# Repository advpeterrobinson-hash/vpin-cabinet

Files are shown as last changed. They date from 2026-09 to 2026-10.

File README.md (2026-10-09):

# Virtual Pinball Cabinet

## [OPEN THE CURRENT GALLERY →](docs/RENDERS.md)

**[ABRIR A GALERIA EM PORTUGUÊS →](docs/pt-BR/RENDERS.md)** · [Português (Brasil)](README.pt-BR.md)

**V35.1 is the current engineering / architectural review. CNC and manufacturing remain BLOCKED.** V32 is historical; passing CAD checks do not certify physical strength, purchased hardware fit or manufacturing readiness.

Parametric virtual pinball cabinet inspired by Williams WPC proportions, developed toward a reproducible flat-pack product with replaceable electronics.

## Current architecture — V35.1

The engineering review is maintained on `feat/v351-cncaudit-qn90f`. Read the [V35.1 technical report](https://github.com/advpeterrobinson-hash/vpin-cabinet/blob/aa3043cd172ed2bf0f05e0ef5ddcf1cbe9b53656/docs/STANDARD_WIDEBODY_V351.md) and [technical package](https://github.com/advpeterrobinson-hash/vpin-cabinet/blob/aa3043cd172ed2bf0f05e0ef5ddcf1cbe9b53656/exports/generated/widebody-v351/README.md). These links pin the reviewed evidence; they do not merge its CAD into `main`.

- Standard widebody: **628.65 mm** external body, **592.65 mm** nominal interior; **1308.10 mm** body length; **780 mm** backbox width.
- **66 wood components: 60 CNC plywood pieces and six solid blocks; 45 families.** Nominal plywood stock is **18 / 12 mm only**; actual lot measurement remains required.
- S1/S2/S3 removable shelves, T1/T2/T3 crossmembers and replaceable guides; low fixed PCBase, **no PC drawer**.
- Retained wooden-dowel/open-cradle playfield architecture. **Primary raised-playfield service support remains unresolved / HOLD**; no service-safety approval is implied.
- Commercial lockdown/receiver reference interfaces; siderails optional. Receiver fit/strategy remains unresolved where it controls permanent machining.
- Local **5 mm tempered playfield glass**, final size after cabinet/channel dry fit; actual side-channel profile and slot coupon still required.
- Real pinball legs; external removable mobility devices, no integrated wheels. Modular electronics and protected grounded mains distribution.

### Selected television — validation pending

**Samsung QN43QN90FAGXZD (QN90F 43-inch)** is the owner-selected purchase target. Selection does not establish compatibility: exact-envelope **PLAY / 0–50° service / 48 mm lift-out and interference checks must be rerun** before the QN90F is described as validated. The permanent cabinet remains intended for replaceable 42/43-inch-class displays.

## Review evidence and release gates

The report records 32 native-CAD review views and passing checks of the modeled reference state. Those results do not certify the selected QN90F, purchased hardware, material strength or human service safety. Preliminary nesting is a study, not production CAM.

**No CNC files are approved for manufacturing. Full-sheet release remains BLOCKED.** Open gates include receiver strategy/fit if machining-dependent; measured side channels and slot coupon; actual plywood lot and tolerance coupon; CNC-provider/tooling parameters and fit regeneration; remaining geometry-controlling hardware/control interfaces and attachment methods; exact QN90F rerun; primary raised-playfield support; and physical load/nudge/glass-edge/thermal qualification.

The lockdown bar and rear glass-channel screw locations are dry-fit interfaces with protected envelopes, not full-sheet CNC gates themselves. F06 reinforcement remains required and is qualified after shell dry fit. See the report for the precise gate boundaries.

## Documentation and history

- [Documentation index](docs/README.md) and [English gallery](docs/RENDERS.md).
- [Historical V32 gallery](https://github.com/advpeterrobinson-hash/vpin-cabinet/blob/feat/cabinet-review-v32/docs/RENDERS.md) and [V32 technical package](https://github.com/advpeterrobinson-hash/vpin-cabinet/blob/feat/cabinet-review-v32/exports/generated/cabinet-v32/README.md): 600 mm architecture, preserved as engineering history.
- [Contradictions and documentary resolutions](docs/PUBLIC_DOCUMENTATION_AUDIT.md).

Older width, gas-strut, sliding-PC and prop studies are historical context, not current V35.1 requirements. Scripts and revision-specific parameters remain engineering authority; no legacy build command on `main` certifies V35.1. Permanent structure should outlive replaceable electronics; adapters and carriers preserve serviceability.

## Open-source hardware

This project is released under the **CERN Open Hardware Licence Version 2 — Strongly Reciprocal (CERN-OHL-S-2.0)**.

Official project / Source Location:

**https://github.com/advpeterrobinson-hash/vpin-cabinet**

Commercial use is allowed. If you convey modified Covered Source or Products based on it, the applicable Complete Source and modifications must remain available under CERN-OHL-S-2.0, and the project Notices / Source Location must be preserved.

In short: **you may build and sell products based on the design, but conveyed improvements may not be turned into a closed proprietary fork.**

See [LICENSE](LICENSE), [NOTICE.md](NOTICE.md), the [open-source policy](docs/OPEN_SOURCE_POLICY.md), the [licensing FAQ](docs/LICENSING_FAQ.md), and [CONTRIBUTING.md](CONTRIBUTING.md).

The licence is intentionally **commercial-friendly but strongly reciprocal**: selling cabinets, kits, fabrication, installation, or support is allowed; when modified Covered Source or Products based on it are conveyed, the applicable Complete Source must stay available under the same reciprocal licence. "Free" here means the design/source remains freely available under the licence — it does **not** require physical products or services to be sold for zero price.

The official upstream project link is part of the project Notice and should remain with redistributed designs/products:

**https://github.com/advpeterrobinson-hash/vpin-cabinet**

## Contributing

Contributions are welcome from builders, CNC operators, mechanical designers, electricians, software developers, testers, and documentation writers.

- Start with [CONTRIBUTING.md](CONTRIBUTING.md).
- Read [GOVERNANCE.md](GOVERNANCE.md) for how engineering decisions are accepted.
- Use the GitHub issue templates for bugs, design proposals, manufacturing feedback, and hardware measurements.
- Use [SUPPORT.md](SUPPORT.md) for help and project-support boundaries.
- Report security or serious safety concerns through [SECURITY.md](SECURITY.md).
- Follow the [Code of Conduct](CODE_OF_CONDUCT.md).
- For reuse, forks, and commercial derivatives, read the [licensing FAQ](docs/LICENSING_FAQ.md).

Useful improvements are encouraged to come back upstream as pull requests, but the legal reciprocal obligations are governed by [LICENSE](LICENSE), not by whether a fork submits a PR.

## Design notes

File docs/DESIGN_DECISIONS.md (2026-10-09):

> **Historical architecture context — superseded by the [current V35.1 review](../README.md).** Earlier widths, display selections, gas-strut/prop and PC-drawer references below are retained for traceability, not current requirements. General safety, serviceability and flat-pack principles remain applicable. CNC/manufacturing remains BLOCKED. See the [documentation audit](PUBLIC_DOCUMENTATION_AUDIT.md).

# Design Decisions

This log records decisions that materially constrain the cabinet design. New decisions should be appended rather than silently rewriting history.

## DEC-001 — Preserve Williams WPC standard-body exterior

**Status:** superseded by DEC-013

Preserve the Williams WPC standard-body external cabinet proportions as the baseline instead of widening the cabinet to make the OLED easier to fit.

Baseline values:

- outer width: 558.80 mm
- side length: 1308.10 mm
- front outside height: 400.05 mm
- rear outside height: 596.90 mm
- rear top flat: 180.975 mm

**Reason at the time:** authentic proportions and compatibility with real-style pinball hardware were initially prioritized over maximizing interior width.

## DEC-002 — Metric plywood redesign

**Status:** accepted

Use nominal 18 mm plywood for the new parametric design instead of retaining the reference model's 19.05 mm / 12.70 mm imperial-stock assumptions.

At 18.00 mm main side thickness and 558.80 mm fixed outer width, nominal cabinet inside width is 522.80 mm.

**Manufacturing note:** the actual measured plywood thickness replaces 18.00 mm before production CNC files are approved.

## DEC-003 — LG OLED42C5 playfield

**Status:** accepted

Use LG OLED42C5 as the initial playfield display.

Engineering envelope used at this stage:

- native width: 932.0 mm
- native height: 540.0 mm
- maximum depth: 41.1 mm
- mass without stand: 9.8 kg
- VESA: 300 x 200 mm

When installed as a pinball playfield, the 540 mm dimension runs across the cabinet and the 932 mm dimension runs front-to-rear.

## DEC-004 — OLED side clearance pocket

**Status:** accepted for the current reference-width engineering baseline; subject to DEC-013 review before manufacturing

Use 1.0 mm nominal clearance per OLED side, yielding a 542.0 mm installed cross-width envelope.

At nominal 18 mm plywood and the historical 558.8 mm body width:

- cabinet inner width: 522.8 mm
- required side pocket depth: 9.6 mm each side
- remaining outer skin: 8.4 mm each side

The side pocket is clearance only. The reduced-thickness plywood is not permitted to carry the OLED or gas-strut structural loads.

## DEC-005 — Structural hinged OLED cradle

**Status:** accepted; geometry pending refinement

The OLED mounts to an independent cradle using its VESA interface. The cradle, not the OLED plastic chassis, carries hinge and lifting loads.

Required service features:

- rear pivot/hinge;
- dual gas struts;
- independent positive mechanical safety restraint/prop;
- controlled opening angle;
- cable service loop and strain relief;
- no slam-shut condition during service.

## DEC-006 — 32-inch 1080p backglass

**Status:** accepted

Use an inexpensive approximately 32-inch 1080p display for backglass duty. The project budget and engineering priority should favor playfield quality, force feedback, audio, and serviceability over backglass resolution.

## DEC-007 — Modular slide-out PC

**Status:** accepted

Use an open ATX metal chassis on a removable/full-extension drawer platform. Current reference chassis envelope is approximately 440 x 265 x 128 mm bare, with a larger reserved service envelope.

The drawer design must support future chassis replacement without redesigning the cabinet shell.

## DEC-008 — Force feedback and SSF are primary subsystems

**Status:** accepted

Mechanical feedback and SSF are design-driving subsystems rather than accessories to be fitted later.

- feedback toys mount rigidly and spatially appropriately;
- SSF-active wall areas remain clear of unnecessary rigid bracing;
- electronics shelves are modular and should avoid degrading cabinet-wall vibration;
- PC/electronics should be isolated from sharp mechanical shock where practical.

## DEC-009 — One external mains cord, multiple internal power domains

**Status:** accepted

The finished cabinet uses one grounded external mains connection and protected internal power distribution.

Operating states:

1. OFF
2. AUDIO ONLY / Bluetooth
3. FULL PINBALL

Audio-only mode must not require the PC, OLED, backglass, or mechanical DOF system to be powered.

## DEC-010 — Normally offline appliance

**Status:** accepted

After setup the cabinet is normally offline. Retain intentional service access through Ethernet and USB passthrough, but normal play must not depend on cloud connectivity.

## DEC-011 — Windows runtime, Linux/FreeCAD engineering

**Status:** provisional/accepted for current planning

Develop the cabinet CAD/tooling on Linux with FreeCAD and Git. The finished pinball computer is presently planned around Windows because the complete VPX/PinUP Popper/legacy DOF ecosystem is more mature there.

This decision may be revisited if the Linux pinball ecosystem reaches equivalent compatibility before software commissioning.

## DEC-012 — Cutter CNC consultation

**Status:** accepted

Cutter CNC (`cuttercnc.com`, Brazil) is the prospective CNC fabrication provider. Before manufacturing files are frozen, confirm their preferred file/layer conventions, available tooling, internal-radius requirements, two-sided registration process, material sourcing, and practical tolerances.

## DEC-013 — Future-proof electronics envelopes over exact historical dimensions

**Status:** accepted; supersedes DEC-001 where there is a conflict

The cabinet and structural metalwork are expected to outlive multiple generations of TVs, PC hardware, controller boards, amplifiers, and power supplies. Exact Williams dimensions are therefore a design reference rather than a manufacturing mandate.

The owner explicitly approves approximately **10–50 mm** dimensional deviations where they materially improve:

- future replacement compatibility;
- service access;
- structural margin;
- cable/connector access;
- modular mounting;
- availability of generic replacement hardware.

Permanent structure should use service envelopes and replaceable interfaces. Component-specific geometry should move into replaceable carriers, bezels, filler panels, and adapters where practical.

The main playfield cabinet width was subsequently selected at **580 mm** under DEC-015 to provide a larger future 42-inch-class service envelope while retaining the Williams visual character.

## DEC-014 — Future-proof backbox width and modular monitor carrier

**Status:** accepted for v0.6 engineering

Increase the backbox target outer width from the 730.25 mm reference to **780.0 mm**. This +49.75 mm deviation intentionally uses the owner-approved tolerance to avoid locking the cabinet to unusually narrow 31.5–32 inch displays.

Target monitor service envelope:

- width: 740 mm
- height: 450 mm
- depth: 100 mm

The permanent shell uses a removable/slotted monitor carrier plus a removable cosmetic bezel/filler panel. The exact backglass model is therefore not required before the permanent backbox shell is CNC-cut; it is only required before its carrier and bezel are finalized.

## DEC-015 — 580 mm CNC-flatpack main body

**Status:** accepted engineering baseline

Adopt **580.0 mm** as the main cabinet outer-width engineering baseline. The goal is not millimetre-perfect Williams replication; the goal is a long-lived, future-proof cabinet that can be replicated from CNC plans.

The target future playfield service envelope is approximately 560 × 950 × 55 mm with 2 mm installation clearance per side. The initial LG OLED42C5 remains comfortably inside that envelope.

A custom-width lockdown bar is explicitly acceptable and is not a blocker. Siderails, brackets, and other simple metal parts may likewise be supplied as dimensioned DXF/PDF fabrication drawings so a local shop can make them without requiring the builder to own metalworking equipment.

The final project should be buildable in an apartment from outsourced CNC/fabricated parts using ordinary hand tools rather than table saws, routers, drill presses, or welding equipment.

## DEC-016 — Replaceable service-I/O fascias with vintage white engraving

**Status:** accepted for v0.8 engineering

Use three service/control zones:

1. separated rear power fascia;
2. rear low-voltage service-I/O fascia;
3. hidden coin-door and under-front service/control panels.

Permanent cabinet panels receive simple rectangular service-bay openings. Connector-specific geometry belongs on small replaceable fascias/carriers so USB, HDMI, network, and other standards can be changed years later without recutting the cabinet.

The visual language is intentionally inspired by vintage hi-fi / laboratory equipment: dark wood or black-finished wood with shallow **white-filled CNC engraving** for connector names, borders, scales, and service legends.

Initial rear service ports are:

- RJ45 Ethernet (`NETWORK`);
- HDMI diagnostic output (`SERVICE DISPLAY`);
- USB-A (`USB SERVICE`);
- USB-C;
- one blank `RESERVE` position.

The rear mains bay remains physically separated and internally enclosed; the decorative wooden fascia is not relied upon as the electrical safety enclosure.

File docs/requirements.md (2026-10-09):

> **Historical architecture context — superseded by the [current V35.1 review](../README.md).** Earlier widths, display selections, gas-strut/prop and PC-drawer references below are retained for traceability, not current requirements. General safety, serviceability and flat-pack principles remain applicable. CNC/manufacturing remains BLOCKED. See the [documentation audit](PUBLIC_DOCUMENTATION_AUDIT.md).

# Cabinet Requirements

## Cabinet

Williams WPC standard-body proportions.

Main structural material:
- Metric plywood
- Nominal target: 18 mm
- Final CAD value must follow measured sheet thickness

Construction must prioritize:
- CNC cutting
- Self-aligning joints
- Minimal manual routing/drilling
- Modular service access
- Replaceable components

## Playfield

LG OLED42C5.

Requirements:
- Rigid independent cradle
- VESA-supported mounting
- Rear pivot/hinge
- Dual gas struts
- Mechanical safety prop or positive secondary restraint
- Service position approximately 60-75 degrees
- Cable service loop
- Playfield must not be structurally supported by OLED chassis

## Backglass

- Approx. 32-inch
- 1920x1080 acceptable
- Low-cost display preferred
- Removable/replaceable mounting system

## PC

- Open ATX test-bench/mining-style metal chassis
- Approximate known chassis size:
  440 x 265 x 128 mm
- Mounted to removable drawer/platform
- Full-extension locking slides
- GPU secondary support
- PC mechanically isolated from force-feedback structure

## Force Feedback

Priority subsystem.

Reserve mounting positions for:
- Flipper feedback
- Sling feedback
- Bumper/impact feedback
- Knocker
- Shaker
- Gear motor
- Additional DOF toys

Feedback devices should couple mechanically to cabinet structure.

## SSF

Reserve isolated cabinet-wall areas for:
- Front-left exciter
- Front-right exciter
- Rear-left exciter
- Rear-right exciter

Do not bridge these areas unnecessarily with rigid shelves.

## Electronics

Modular removable mounting panels for:
- Main controller
- DOF output boards
- LED controllers
- Powered USB hub
- Audio hardware
- DC distribution

Separate high-current and signal wiring routes.

## Power

One external mains cord.

Modes:
1. OFF
2. AUDIO ONLY
3. FULL PINBALL

Audio-only mode:
- PC OFF
- OLED OFF
- backglass OFF
- mechanical DOF OFF
- Bluetooth receiver ON
- main audio amplifier ON

## Service I/O

Front/underside:
- USB-A
- USB-A
- USB-C
- Hardware master volume

Rear:
- Ethernet
- USB service
- optional HDMI service
- main disconnect

## Mobility

- Real pinball legs
- Real levelers
- Wheels must retract or otherwise leave levelers firmly on floor during play
- Cabinet must remain rigid for nudging

## Manufacturing

Final manufacturing package should include:
- FreeCAD source
- DXF
- SVG where useful
- dimensioned PDF drawings
- assembly drawings
- CNC sheet layouts
- BOM
- electrical drawings

A CNC tolerance/material test coupon must be cut before cabinet production.

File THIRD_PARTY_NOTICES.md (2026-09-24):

# Third-Party Notices

The CERN-OHL-S-2.0 licence applies to original project material unless a file or directory states otherwise.

It does **not** relicense third-party material merely because that material is referenced by this repository.

This project may refer to or interoperate with third-party products, trademarks, dimensions, standards, software, documentation, and hardware, including pinball-industry components and commercial electronics. Those names and materials remain subject to their respective owners' rights and licences.

In particular:

- Williams and other pinball brands are referenced for compatibility, proportions, or historical context only;
- vendor manuals, datasheets, product images, and reference models retain their original copyright/licence status;
- third-party open-source software retains its own licence;
- commercial hardware part numbers do not imply sponsorship or endorsement.

Contributors must not copy proprietary CAD, copyrighted manuals, artwork, ROMs, game assets, trademarks, or other protected material into the project unless redistribution is clearly permitted and the source/licence is documented.

Project releases should prefer original geometry, measurements, interoperability facts, and links to lawful upstream sources rather than redistributing third-party files unnecessarily.

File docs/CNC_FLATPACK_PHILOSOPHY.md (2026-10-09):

> **Historical architecture context — superseded by the [current V35.1 review](../README.md).** Earlier widths, display selections, gas-strut/prop and PC-drawer references below are retained for traceability, not current requirements. General safety, serviceability and flat-pack principles remain applicable. CNC/manufacturing remains BLOCKED. See the [documentation audit](PUBLIC_DOCUMENTATION_AUDIT.md).

# CNC Flat-Pack Build Philosophy

## Primary project objective

The project is not only a one-off virtual pinball cabinet. It is intended to become a reproducible **CNC-first flat-pack cabinet system**.

A builder should be able to:

1. download the released plan package;
2. take the CNC files and material schedule to a local fabrication shop;
3. receive labeled, machined parts;
4. assemble, finish, wire, and commission the cabinet in an apartment or ordinary room;
5. do so without owning expensive woodworking or metalworking machinery.

The design should therefore move precision work from the builder to CAD/CAM and the fabrication shop.

## What the CNC shop should do

Where practical, the CNC package should include all repeatable woodworking operations:

- exterior panel profiles;
- through-cuts;
- dados and rabbets;
- tab/slot alignment geometry;
- pockets for display clearance and hardware;
- speaker, fan, button, coin-door and service openings;
- pilot/reference holes;
- threaded-insert/T-nut locations where appropriate;
- cable-pass openings;
- ventilation geometry;
- removable electronics-panel interfaces;
- PC-drawer mounting references;
- labels/part IDs or engraving marks where useful;
- test coupon for actual material thickness and fit.

Dogbone/T-bone relief and other router-specific geometry should be generated from confirmed provider tooling rather than improvised by the builder.

## What the builder should need

Target ordinary tools only:

- drill/driver;
- screwdrivers / hex keys;
- clamps;
- rubber mallet;
- wood glue;
- measuring tape / square;
- basic sanding and painting supplies;
- wire tools for electrical assembly.

A build step that requires a table saw, router table, precision handheld routing, drill press, welder, planer, or similar equipment should be treated as a design smell unless there is no practical outsourced/CNC alternative.

## Joinery strategy

Prefer joinery that is self-locating and forgiving:

- dados;
- rabbets;
- tabs and slots;
- captured shoulders;
- keyed left/right geometry;
- CNC-located fastener holes.

Avoid requiring the builder to establish critical dimensions by measuring from an edge with a tape measure.

The cabinet should naturally square itself during dry assembly as much as practical.

## Electronics and future replacement

Permanent cabinetry should not be tied to one generation of electronics.

Use broad service envelopes and replaceable interfaces:

- playfield TV: structural cradle + replaceable VESA/adapter plate + removable fillers;
- backglass: replaceable monitor carrier + replaceable bezel/filler panel;
- PC: fixed drawer infrastructure + replaceable chassis adapter plate;
- controllers/amplifiers/PSUs: removable electronics panels or grid/slot mounting;
- external ports: replaceable I/O panel;
- DMD/speaker area: replaceable module/panel.

Replacing electronics should normally require a new adapter/filler part, not destructive modification of the permanent cabinet.

## Metal parts

Custom metalwork is acceptable if it can also be outsourced from drawings.

Examples:

- custom-width lockdown bar;
- siderails;
- hinge brackets;
- gas-strut brackets;
- PC drawer brackets;
- wheel/retractable-caster mechanisms;
- service/I/O panels.

Where practical, provide DXF plus dimensioned PDF and fabrication notes so a local laser-cutting/bending/welding shop can reproduce the part.

The builder should not be expected to own metalworking machinery.

## Release package goal

A mature release should contain at least:

```text
release/
├── README-FIRST.pdf
├── BOM.xlsx
├── materials.pdf
├── assembly-manual.pdf
├── cnc/
│   ├── 18mm-sheet-01.dxf
│   ├── 18mm-sheet-02.dxf
│   ├── 12mm-sheet-01.dxf
│   ├── tolerance-coupon.dxf
│   └── layer-conventions.pdf
├── drawings/
│   ├── cabinet.pdf
│   ├── backbox.pdf
│   ├── playfield-cradle.pdf
│   └── electronics-layout.pdf
├── metal/
│   ├── lockdown-bar.dxf
│   ├── lockdown-bar.pdf
│   ├── hinge-brackets.dxf
│   └── hinge-brackets.pdf
└── config/
    └── design-baseline.json
```

The exact structure may evolve, but the final user should not need FreeCAD merely to build the cabinet.

## Design priority order

When objectives conflict, use this order unless safety requires otherwise:

1. safety;
2. reproducibility;
3. CNC manufacturability;
4. easy assembly with ordinary tools;
5. serviceability and future electronics replacement;
6. force-feedback/audio performance;
7. authentic Williams visual character;
8. millimetre-perfect historical dimensions.

This means a small dimensional deviation is desirable when it materially simplifies fabrication, strengthens the structure, improves replacement tolerance, or eliminates specialist-tool work at home.

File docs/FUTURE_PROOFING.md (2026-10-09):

> **Historical architecture context — superseded by the [current V35.1 review](../README.md).** Earlier widths, display selections, gas-strut/prop and PC-drawer references below are retained for traceability, not current requirements. General safety, serviceability and flat-pack principles remain applicable. CNC/manufacturing remains BLOCKED. See the [documentation audit](PUBLIC_DOCUMENTATION_AUDIT.md).

# Future-proofing policy

## Owner direction

The cabinet is expected to last much longer than its televisions, PC, controllers, amplifiers, and power electronics. Exact historical Williams dimensions are therefore secondary to long-term serviceability and replacement-part compatibility.

The owner explicitly accepts approximately 10–50 mm dimensional deviations when they materially improve the design.

## Permanent structure vs replaceable electronics

Permanent wood and metal structure should be sized around service envelopes and modular interfaces. Electronics-specific geometry belongs in replaceable parts where practical.

Preferred pattern:

- permanent shell: generous service envelope;
- replaceable carrier/adapter: actual VESA or chassis pattern;
- replaceable bezel/filler: closes cosmetic gaps;
- slotted mounting where practical;
- cable service loops and accessible connectors;
- no trapped electronics behind irreversible joinery.

## Backbox

The authentic reference backbox is 730.25 mm wide. This is too restrictive for many modern 31.5–32 inch displays.

v0.6 therefore targets 780 mm outer width and a 740 x 450 x 100 mm monitor service envelope. This is a deliberate +49.75 mm deviation from the reference width and remains within the owner-approved future-proofing allowance.

The exact backglass monitor is no longer required before cutting the permanent backbox shell. Only its replaceable monitor carrier and cosmetic bezel depend on the exact purchased model.

## Main playfield cabinet

The current 558.8 mm Williams reference body fits the selected LG OLED42C5 but leaves little cross-width growth margin once an 8 mm side skin is preserved.

Before main-cabinet dimensions are frozen, evaluate a modest width increase against:

- future 42-inch-class display chassis widths;
- desired minimum side skin;
- playfield glass sourcing;
- lockdown-bar sourcing/fabrication;
- siderail sourcing/fabrication;
- hinge/cradle width;
- flipper/button ergonomics;
- Williams visual proportions.

A likely evaluation range is roughly 570–575 mm external body width, but no new body width is approved until hardware consequences are checked parametrically.

## PC and electronics

The existing open-frame ATX chassis is an initial component, not a permanent dimensional constraint. The drawer uses a service envelope and a replaceable chassis adapter.

Controller boards, amplifiers, power supplies, and DOF boards should mount to removable grid/slotted panels or DIN-style subassemblies where appropriate so future boards can change size without cabinet surgery.

## Manufacturing rule

Do not spend structural margin merely to reproduce a historical dimension when 10–50 mm of additional envelope materially reduces future replacement risk.

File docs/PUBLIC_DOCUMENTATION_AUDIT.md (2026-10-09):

# Public documentation audit — V35.1

Audit performed before editing the public entry points. Main baseline: `2eed36e4ff6e0871edc4d7d845288c5a629fd8b9`. Engineering evidence: [`aa3043cd172ed2bf0f05e0ef5ddcf1cbe9b53656`](https://github.com/advpeterrobinson-hash/vpin-cabinet/blob/aa3043cd172ed2bf0f05e0ef5ddcf1cbe9b53656/docs/STANDARD_WIDEBODY_V351.md) on `feat/v351-cncaudit-qn90f`.

| Location before correction | Contradiction | Documentary resolution |
|---|---|---|
| main README.md and README.pt-BR.md | V32 called current; 600 mm body / 564 mm interior; links to V32 gallery | Identify V35.1 as current engineering review, 628.65 / 592.65 mm; retain V32 as history |
| main README.md and README.pt-BR.md | Captive props described as current mechanism | Do not prescribe an unqualified support; V35.1 primary raised-playfield support remains HOLD |
| Engineering-branch README.md | Opening says CURRENT V35.1, later headings say current V32; active design still lists 600 mm, custom lockdown and sliding CPU shelf | Main entry points link directly to pinned V35.1 report/package rather than treating the mixed branch README as authority |
| Engineering-branch docs/RENDERS.md and docs/pt-BR/RENDERS.md | V35.1, V34, V33.8 and V32 all called current | Provide bilingual main gallery pages with a single current V35.1 entry and explicitly historical V32 links |
| main AGENTS.md | 580 mm, LG C5, mandatory gas struts, PC drawer and play-isolated wheels | Add explicit current-review precedence; preserve old baseline instructions as historical evidence |
| main docs/FUTURE_PROOFING.md, docs/requirements.md, docs/DESIGN_DECISIONS.md and docs/CNC_FLATPACK_PHILOSOPHY.md | Older width studies, gas struts and drawer references read as active requirements | Mark superseded architecture context; general safety/flat-pack principles remain applicable |
| V35.1 report: passing motion checks vs QN90F purchase selection | Modeled reference checks could be mistaken for exact QN90F validation | Preserve exact-envelope PLAY / 0–50° / 48 mm lift-out rerun requirement; purchase selection is not validation |

## Scope and precedence

This correction targets `main` with documentation only. Engineering-branch README/gallery contradictions remain recorded above; their contents are not imported or rewritten by this PR. The pinned V35.1 technical report and generated package provide revision-specific evidence. Existing V32 and earlier artifacts remain historical, including their original validation results; those results do not transfer to V35.1.

No geometry, parameters, BOM, CAD, generated views or manufacturing files are changed. No engineering branch is merged. V35.1 identifies the current review, not a CNC-approved product. CERN-OHL-S-2.0, notices and contribution rules remain unchanged.

## Gates preserved

Exact Samsung QN43QN90FAGXZD envelope and service-motion/interference validation; primary raised-playfield support; receiver strategy/fit where it controls machining; measured side-channel profile and slot coupon; plywood lot/tolerance coupon; provider/tooling and fit regeneration; remaining permanent hardware/control interfaces and attachment methods; physical load, nudge, glass-edge and thermal qualification. Full-sheet CNC release remains **BLOCKED**.

Lockdown-bar and rear-channel screw locations are dry-fit interfaces with protected envelopes, not full-sheet CNC gates in themselves. F06 reinforcement is required but its jig/screw qualification follows shell dry fit; final 5 mm glass cutting follows cabinet/channel dry fit. Do not broaden these into unnecessary pre-CNC purchasing gates.

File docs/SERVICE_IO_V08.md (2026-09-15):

# Service I/O v0.8 — vintage engraved rear panels

Status: engineering provisional; not manufacturing-ready.

## Design intent

The external I/O should look like part of the cabinet rather than like a PC case. The chosen visual language is inspired by older hi-fi receivers, amplifiers, laboratory equipment, and arcade hardware: dark wood/black surfaces with small white legends, borders, scales, and connector names.

The cabinet is still a CNC-flatpack project, so the appearance must not depend on difficult hand fabrication. Precision openings and engraving belong in the CNC package; the builder should only need finishing, simple paint fill, and ordinary screw assembly.

## Core construction rule

Do **not** cut today's USB/HDMI/RJ45 connector shapes directly into permanent cabinet structure.

Instead use:

1. one simple rectangular CNC opening in the permanent rear panel;
2. a removable CNC-cut decorative wood fascia;
3. a thin replaceable connector carrier behind the fascia;
4. panel-mount pass-through connectors on the carrier;
5. CNC-engraved white-filled legends on the fascia.

If interface standards change later, the owner replaces the small fascia/carrier assembly rather than modifying the cabinet.

## Rear layout

Viewed from behind the 580 mm cabinet:

```text
┌──────────────────────────────────────────────────────────┐
│                                                          │
│                        REAR                              │
│                                                          │
│                                                          │
│   ┌────────────────┐        ┌────────────────────────┐   │
│   │    AC MAINS    │        │        SERVICE         │   │
│   │                │        │                        │   │
│   │ inlet / cord   │        │ NETWORK   HDMI         │   │
│   │ disconnect     │        │ USB-A     USB-C        │   │
│   │                │        │ RESERVE                │   │
│   └────────────────┘        └────────────────────────┘   │
│                                                          │
└──────────────────────────────────────────────────────────┘
```

### Power fascia

- 170 × 120 mm removable decorative fascia
- 35 mm from cabinet left edge
- 40 mm above cabinet bottom
- cabinet window: 150 × 100 mm
- internal enclosed mains compartment mandatory
- engraved legends: `AC MAINS` and `MASTER DISCONNECT`

The wood fascia is decorative/mechanical only. It is **not** relied upon as the mains-voltage safety enclosure.

### Service I/O fascia

- 255 × 120 mm removable fascia
- 35 mm from cabinet right edge
- 40 mm above cabinet bottom
- cabinet window: 235 × 100 mm
- thin 3 mm replaceable connector carrier behind it

Initial ports:

- `NETWORK` — RJ45 Ethernet
- `SERVICE DISPLAY` — HDMI diagnostic output
- `USB SERVICE` — USB-A
- `USB-C` — USB-C data/service
- `RESERVE` — blank standardized position

The 85 mm gap between the two fascia envelopes is deliberate. Mains and low-voltage/data wiring remain separated internally.

## Why the service-display HDMI exists

The rear HDMI jack is not for normal gameplay. It is an emergency/service video path. If the playfield display or its mounting system is unavailable years later, a normal monitor can be plugged into the cabinet without dismantling the playfield assembly merely to troubleshoot the PC.

## Coin-door service panel

A hidden panel inside the coin door provides frequently needed technician access without opening the playfield:

- USB-A ×2
- USB-C ×1
- 3.5 mm AUX IN
- DOF / mechanical-feedback `SERVICE DISABLE`
- PC `POWER`
- PC `RESET`

Header engraving: `CABINET SERVICE`.

The feedback-disable control must act on the mechanical-feedback enable path independently of ordinary software control.

## Hidden front controls

A small panel under the front edge, hidden from normal standing view, carries:

- hardware master-volume knob
- three-position `OFF / AUDIO / PINBALL` selector
- `BLUETOOTH PAIR` button
- optional `USB-C CHARGE`

The volume knob gets a simple white engraved scale/tick ring in the same visual style as vintage audio equipment.

## Engraving specification

Target appearance:

- dark satin black or very dark brown wood finish;
- shallow CNC engraving;
- white enamel/paint fill;
- uppercase geometric sans-serif legends;
- simple rectangular separator lines and volume tick marks;
- no decorative clutter that makes service labels harder to read.

Engineering starting point:

- 0.6 mm nominal engraving depth;
- 0.6 mm minimum visible stroke;
- 60-degree V-bit preferred;
- text converted to curves/outlines in released fabrication files.

If a CNC provider cannot V-engrave, the release may also contain a 1 mm end-mill engraving layer or laser-engraving alternative. The geometry, labels, and layer names should remain the same.

White filling is intentionally a low-tool operation: enamel, model paint, paint marker, or another durable white infill can be applied after the dark finish and wiped/sanded back as appropriate to the finishing system.

## Panel standardization

Where practical, use standardized panel-mount/pass-through connector footprints on the thin carrier rather than permanently committing the wooden fascia to one connector brand. Candidate families include standardized circular/D-series-style mounting or keystone/pass-through modules, but the final connector family remains a BOM-stage decision.

The permanent cabinet should only know the **service-bay rectangle and mounting-hole pattern**.

## CNC release requirements

The eventual CNC package should expose separate layers/operations for:

- `CUT_THROUGH`
- `POCKET`
- `DRILL`
- `ENGRAVE_WHITE`
- `REFERENCE_DO_NOT_CUT`

The service fascia should be a standalone numbered part, so a future owner can order only that part from a CNC shop without recutting the rear cabinet panel.

## Safety

- Mains and signal/data fascia bays are physically separated.
- Mains terminals are enclosed behind the decorative panel.
- Rear low-voltage connectors should be electrically isolated from mains hardware as required.
- Mechanical-feedback disable is accessible without entering the mains compartment.
- No service connector should require the builder to expose live mains wiring during ordinary use.

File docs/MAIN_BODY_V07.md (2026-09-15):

# Main body v0.7 — Future playfield replacement envelope

Status: engineering study; not manufacturing-ready.

## Goal

Avoid building the permanent cabinet around the exact 540 mm cross-width of the first LG OLED42C5. The cabinet should have a realistic path to accept meaningfully larger future 42-inch-class displays without destructive structural modification.

## Target replacement envelope

Provisional service envelope for the future playfield display:

- cross-cabinet chassis width: **560 mm**
- front-to-rear chassis length: **950 mm**
- maximum depth/bulge: **55 mm**
- assembly clearance: **2 mm per side**
- minimum structural side skin at a routed pocket: **8 mm**

The 560 mm width target is 20 mm wider than the initial C5 chassis dimension used across the cabinet. It is deliberately not tied to one brand/model and gives more useful growth margin than designing around a few spare millimetres.

## Width candidates

The historical Williams reference body is 558.8 mm wide. Candidate external widths under study are:

- 558.8 mm reference
- 565 mm
- 570 mm
- 575 mm
- **580 mm preferred study candidate**

At 18 mm nominal side material and an 8 mm minimum remaining side skin, the maximum future display cavity is effectively `outer width - 16 mm`.

For a 560 mm chassis plus 2 mm clearance per side, the required cavity is 564 mm. Therefore the theoretical minimum body width is **580 mm**.

This is why 580 mm is the current preferred study candidate. It is only +21.2 mm wider than the Williams reference—well inside the owner-approved dimensional tolerance—but increases the future cross-width capability by 20 mm relative to the initial LG C5 chassis.

## Do not freeze 580 mm yet

Before changing the master CAD width, review the consequences for:

- lockdown bar sourcing or custom fabrication;
- playfield glass width/cut-to-size availability;
- siderail sourcing or fabrication;
- front flipper/magna-save button ergonomics;
- leg/bracket geometry;
- coin-door/front panel proportions;
- playfield cradle crossmembers and hinge axis;
- backbox overhang/proportion with the new 780 mm future-proof backbox.

If these impacts are minor or solvable with custom/standard metalwork, 580 mm should replace 558.8 mm as the permanent body width before CNC freeze.

## Modular playfield assembly

Even with a wider body, the playfield system should remain modular:

- structural cradle independent of the TV shell;
- replaceable VESA/adapter plate;
- slotted mounting where possible;
- removable side/filler pieces;
- cable service loop with accessible power/HDMI;
- no TV-specific permanent wood holes except broad clearance pockets.

The objective is to replace a future display with a new adapter/filler set, not rebuild the cabinet.

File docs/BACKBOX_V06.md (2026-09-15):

# Backbox v0.6 — Future-proof 32-inch-class Display Packaging

Status: engineering provisional; not manufacturing-ready.

## Design philosophy

The cabinet is expected to outlive several generations of electronics. The backbox therefore must not be dimensioned around one exact monitor chassis.

Williams geometry is a visual/proportional reference, not an absolute constraint. The owner explicitly allows approximately 10–50 mm dimensional deviations where they materially improve serviceability, replacement-part availability, or long-term compatibility.

Reference-model backbox envelope:

- 730.25 mm outer width
- 254.00 mm depth
- 723.90 mm height

Future-proof target backbox envelope:

- **780.00 mm outer width**
- 254.00 mm depth initially retained
- 723.90 mm height initially retained
- nominal 18 mm side material
- resulting nominal internal width: **744.00 mm**

The +49.75 mm width change is intentionally near the upper end of the owner-approved tolerance because width is the limiting dimension for generic 31.5–32 inch displays. Height and depth already have substantial margin.

## Electronics service envelope

The permanent backbox shell should accommodate a replaceable monitor chassis envelope of approximately:

- width: **740 mm**
- height: **450 mm**
- depth: **100 mm**

At 780 mm outer width with 18 mm sides, a 740 mm chassis envelope retains 2 mm nominal assembly clearance on each side.

This service envelope is more important than matching the original Williams backbox width exactly.

## Replaceable assembly strategy

The permanent wood shell must not contain monitor-specific VESA holes or a monitor-specific front opening where avoidable.

Use:

1. a removable/slotted VESA monitor carrier;
2. a removable front bezel/filler panel matched to the installed monitor;
3. replaceable spacers/filler strips where needed;
4. cable service loops and connector access independent of the monitor model.

As a result, the exact monitor model is **not required before the main backbox shell is CNC-cut**. The exact model is required only before the replaceable carrier/bezel is finalized.

## Current examples

- LG 32SR50F-W: 731.8 mm wide without stand — too wide for the authentic 730.25 mm shell, but comfortably within the new 740 mm service envelope.
- Mancer Valak UZ32: approximately 715 mm wide — comfortably within the service envelope.
- Duex 31.5-inch model: retailer-listed near 713 mm — also within the service envelope, but exact dimensions still require confirmation before making its carrier/bezel.

## Procurement policy

Backglass remains a cost-controlled subsystem. Desired characteristics:

- approximately 31.5–32 inch diagonal;
- 1920×1080 sufficient;
- flat panel strongly preferred;
- VESA preferred;
- chassis width <= 740 mm preferred;
- chassis height <= 450 mm preferred;
- chassis depth <= 100 mm preferred;
- HDMI input;
- exact carrier/bezel generated only after the actual display is selected or measured.

## Future-proofing principle

Do not force permanent cabinetry to conform tightly to short-lived electronics. Where a modest dimensional change improves the probability of finding replacement hardware years later, prefer the dimensional allowance and preserve the Williams visual language rather than exact historical dimensions.

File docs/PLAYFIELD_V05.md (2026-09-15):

# Playfield Service v0.5 — Sweep, Backbox Keepout, and Positive Safety

## Purpose

v0.5 turns the successful v0.4 hinge concept into a more useful serviceability
model. It remains an engineering packaging stage and is **not** approved for
manufacturing.

## Added in v0.5

- OLED sweep ghosts at 0, 10, 20, 30, 40, 50, 60, and 70 degrees.
- Conservative backbox keepout envelope based on reference-model dimensions.
- Automated sweep-vs-backbox intersection checks.
- Rear hinge reinforcement/crossmember envelope tied to full-thickness cabinet regions.
- VESA carrier adjustment zone without invented hole locations.
- Independent positive mechanical safety-prop packaging candidate.
- Candidate gas-strut comparison at 250 N, 275 N, and 300 N per side.
- Headless verification of generated solids and collision state.

## Important limitations

### Backbox

The backbox *dimensions* originate from the audited reference model, but its
placement in v0.5 is intentionally conservative/provisional. Before final CAD,
we must either extract the actual reference placement or lock the exact
backbox/hinge hardware we will use.

### VESA

The LG C5 VESA pattern is known as 300 x 200 mm, but its chassis-relative centre
is not assumed. v0.5 therefore shows an adjustment zone only. No manufacturing
hole locations are generated.

### Gas struts

250/275/300 N are analytical candidates, not a shopping list. Final selection
requires actual cradle mass, actual combined centre of gravity, hinge bracket
geometry, available commercial lengths/strokes, and a practical safety margin.

### Safety prop

The v0.5 prop is a packaging envelope for an independent positive mechanical
support. The final device should be captive, easy to engage during service,
and mechanically able to hold the assembly even if both gas struts fail.
Possible final implementations include a pinned prop bar or a purpose-built
locking lid stay. The v0.5 model does not approve material section or pin size.

## Local validation

```bash
cd ~/Projetos/vpin-cabinet
git fetch origin
git switch feat/playfield-v05
git pull
bash tools/run_playfield_v05.sh
```

Successful output must include:

- baseline validation passes;
- v0.5 sweep/safety solver passes;
- v0.4 base geometry regenerates;
- v0.5 geometry generates;
- all sweep states clear the provisional backbox keepout;
- safety-prop envelope is within the initial packaging range;
- headless FreeCAD verification passes.

After that, open `cad/master/vpin-master.FCStd` and inspect the group:

`PLAYFIELD SERVICE v0.5 - SWEEP / SAFETY`

## Merge gate

Do not merge v0.5 if the local runner fails. Visual inspection should confirm
that the sweep ghosts form a plausible upward service arc, the backbox keepout
is behind the playfield, and the safety prop spans from a cabinet-side fixed
point to the raised cradle without obviously crossing the OLED body.

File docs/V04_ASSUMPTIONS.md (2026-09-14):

# v0.4 assumptions requiring later replacement

1. OLED/front longitudinal placement remains the 44.4 mm reference-derived setback.
2. Glass clearance is provisionally 12 mm normal to the playfield plane.
3. Cradle mass is estimated at 3.0 kg.
4. Combined OLED+cradle CG is approximated at the OLED longitudinal midpoint.
5. Cradle rail sections are only 20 x 20 mm packaging envelopes; alloy/wall thickness not selected.
6. Hinge axis is provisionally 35 mm behind the OLED rear edge.
7. Gas-strut attachment coordinates and 300 N candidate force are optimization seeds, not purchasing values.
8. Exact LG VESA-hole offsets from chassis edges are not assumed.
9. Backbox collision geometry is not yet part of the generated master and is a v0.5 validation requirement.
10. OLED side-wall pocket geometry remains uncut in this stage; the previously validated 9.6 mm nominal pocket requirement is a packaging value only.

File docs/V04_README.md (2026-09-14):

# Playfield v0.4 quickstart

This branch introduces a provisional hinged-playfield kinematic model.

Run locally:

```bash
git fetch origin
git switch feat/playfield-v04
git pull
bash tools/run_playfield_v04.sh
freecad cad/master/vpin-master.FCStd
```

The generated FreeCAD group is `PLAYFIELD SERVICE v0.4 - PROVISIONAL`.

A successful script run plus a mechanically sensible upward-opening ghost is the validation gate for merging this branch. The branch does not contain manufacturing approval.

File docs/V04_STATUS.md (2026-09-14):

# v0.4 validation status

Current status: **AWAITING LOCAL FREECAD VALIDATION**.

Repository-side preparation is complete. Merge is intentionally blocked until the one-command local run succeeds and the generated open-position geometry is visually confirmed to rotate upward around the rear hinge.

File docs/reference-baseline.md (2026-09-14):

# Reference Cabinet Baseline

Source:
dekay/vpin-cabinet reference model
vpin-cabinet-2026-02-16.FCStd

This file records dimensions extracted from the reference model.
They are reference values only and are NOT automatically approved
manufacturing dimensions.

## Williams-style cabinet reference

Main cabinet side:
- Material thickness: 19.05 mm
- Length envelope: 1308.10 mm
- Height envelope: 596.90 mm

Cabinet external width reference:
- 558.80 mm

Cabinet internal width reference:
- 520.70 mm

Relationship:
520.70 + (2 x 19.05) = 558.80 mm

## New metric design decision

Preserve Williams external width:
- 558.80 mm

Use nominal metric plywood:
- 18.00 mm initially

Resulting nominal inside width:
- 522.80 mm

Actual plywood thickness will replace nominal 18.00 mm after
measuring the material selected for production.

## Backbox reference

Overall reference bounding box:
- Width: 730.25 mm
- Depth: 254.00 mm
- Height: 723.90 mm

## Reference playfield display

Reference model TV envelope:
- Cross-cabinet dimension: 533.40 mm
- Long dimension: 932.00 mm
- Thickness: 36.10 mm

This is NOT assumed to match the selected LG OLED42C5.

Reference playfield TV mount:
- Width: 535.78 mm
- Length: 1093.79 mm
- Thickness: 12.70 mm

## Reference internal components

Controller shelf board:
- 514.35 x 171.45 x 12.70 mm

Computer shelf:
- 355.60 x 406.40 x 12.70 mm

These are layout references only.

## Parametric redesign rules

Our FreeCAD master must use a Spreadsheet parameter source.

The existing reference model contains no Spreadsheet::Sheet objects.

The new model will separate:
- Williams external dimensions
- measured material dimensions
- OLED envelope
- manufacturing clearances
- CNC cutter dimensions
- hardware dimensions
- force-feedback zones
- electronics/service envelopes

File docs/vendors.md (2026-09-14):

# Parts and Services Vendors

## CNC Fabrication

### Cutter CNC

Website: https://www.cuttercnc.com/

Location:
São Paulo - SP, Brazil

Status:
Prospective CNC fabrication provider.
Consult before finalizing manufacturing files.

Services relevant to this project:
- CNC router cutting
- Pocket/recess machining
- Drilling
- Engraving
- 2D machining
- 3D machining where required

Supported project materials include:
- Plywood / compensado
- Marine plywood / compensado naval
- MDF
- MDP
- Solid wood
- Acrylic
- Polycarbonate
- PVC and various engineering plastics

Published machine capacity:
- Maximum length: 3000 mm
- Maximum width: 2000 mm
- Maximum machining height: 200 mm

Project-file requirements:
- Files should be supplied at 1:1 actual size
- Material must be specified
- Material thickness must be specified

Published supported formats include:

2D:
- DXF/DWG
- PDF
- EPS
- AI/CDR

3D:
- STL
- 3DM
- DXF
- OBJ
- other supported CAD formats

Important:
- Provider performs cutting/machining only.
- Painting, coating, polishing and final finishing are not included.
- Final tool diameter, tolerances, kerf/offset strategy,
  dogbone requirements and plywood measured thickness must be
  confirmed with the provider before generating production files.

Project intent:
Use Cutter CNC for an early design-for-manufacture consultation
before the cabinet CAD is frozen, and later obtain a quotation for
the CNC-cut cabinet kit.

Questions for consultation:
1. Preferred production file format: DXF or DWG?
2. Preferred layer convention for:
   - through cuts
   - pockets
   - drilling
   - engraving
3. Available router bit diameters.
4. Minimum practical internal radius.
5. Whether dogbones should be drawn by us or generated by CAM.
6. Typical dimensional tolerance in 18 mm plywood.
7. Whether they source plywood or require customer-supplied sheets.
8. Recommended plywood grade for painted cabinetry.
9. Whether both-face machining is available.
10. Method used for registration when machining both faces.
11. Minimum spacing required between nested parts.
12. Whether tabs/bridges should be included in our drawing or their CAM.
13. Cost difference between simple 2D cutting and pocket/dado machining.
14. Whether they can drill pilot holes and threaded-insert locations.
15. Maximum acceptable file size and preferred FreeCAD export workflow.

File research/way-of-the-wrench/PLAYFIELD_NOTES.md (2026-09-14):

# Playfield-related research notes

This file is intentionally concise. The Way of the Wrench playlists are research references, not dimensional authorities for this cabinet.

For the playfield-service subsystem, the useful design themes are:

- service access must be planned before filling the cabinet with electronics and feedback toys;
- removable/accessible mounting is preferable to burying hardware under the display;
- high-end virtual-pinball builds accumulate substantial wiring, controllers, lighting, and feedback hardware, so the raised playfield must expose a deliberate service volume rather than merely lift a screen;
- wiring should be labeled and routed with disconnection/service in mind;
- force-feedback and SSF locations should be reserved early because later shelves and braces can compromise them.

Our design intentionally goes beyond the reference builds by requiring a structural LG C5 cradle, dual gas struts, an independent positive mechanical safety support, and a slide-out PC module. No hinge/strut dimension is copied from the videos without independent engineering validation.

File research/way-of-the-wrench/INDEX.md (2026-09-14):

# Way of the Wrench research index

This folder tracks research from the two Way of the Wrench virtual-pinball build series selected as reference material for this cabinet.

## Playlists

### Original scratch / wallet-friendly cabinet build

- Playlist ID: `PLrqlHbqP7FIO5P8e8HtrBB01xqQtAWpJ5`
- Entry video supplied by project owner: `JxilHoceiNo`
- Role in this project: cabinet construction, dimensional/layout choices, practical build sequence, lessons learned, serviceability, wiring and baseline VPIN architecture.

### Big Budget VPin

- Playlist ID: `PLrqlHbqP7FINmGgJoszVvWOOyb8shdfUn`
- Entry video supplied by project owner: `iXeMTjJhAJQ`
- Role in this project: high-end flat-pack build, DOF/feedback toys, controller boards, addressable lighting, power distribution, wiring, cable management, serviceable modules and no-expense-spared hardware choices.

## Verified companion material

The creator's South Delta Secondary School / Way of the Wrench resource page publishes downloadable cabinet configuration files for both generations of the project. The original cabinet configuration includes Teensy-controlled addressable strips for left/right playfield, matrix, speakers, under-cabinet and backbox lighting. The September 2025 Big Budget cabinet configuration uses a Wemos D1 Mini Pro-style strip controller setup and defines a much larger addressable-lighting layout including a 96x16 matrix, left/right playfield strips, backbox, speaker, under-cabinet, magna-save and flipper lighting.

A Pinball Lunatics guide page independently identifies the later series as `Big Budget VPin`, describes it as a high-end build based on a flat-pack cabinet, and notes that it follows the earlier wallet-friendly build.

Community build logs repeatedly cite the original Way of the Wrench playlist as a primary cabinet-design/build reference. This makes the series useful not merely as inspiration but as a practical source whose decisions can be cross-checked against other VPIN builds and the Pinscape guide.

## Research method

Do not ingest every video in full into normal chat context. Research is subsystem-driven:

1. Cabinet / woodworking / dimensions
2. Playfield mounting and service access
3. Power, fusing, grounding and switching
4. Main controller / plunger / nudge / inputs
5. DOF output boards
6. Mechanical feedback toys
7. SSF and main audio
8. Addressable LEDs / matrix / flashers
9. Cable routing, connectorization and serviceability
10. PC / cooling / display layout
11. Software/frontend only where it affects hardware design

For each subsystem classify observations as:

- `ADOPT`: directly applicable
- `ADAPT`: useful concept but must be changed for our CNC/OLED/service design
- `REJECT`: inferior, obsolete, unsafe or incompatible with project goals
- `VERIFY`: needs a primary hardware manual or independent source before design use

## Project-specific differences to preserve

The Way of the Wrench designs are references, not masters. Our design intentionally differs in several areas:

- Williams WPC standard-body exterior geometry retained
- 18 mm metric plywood and CNC-first joinery
- LG OLED42C5 playfield
- hinged structural VESA cradle with dual gas struts and independent mechanical safety support
- open-frame ATX PC on a service drawer
- modular isolated electronics shelves and mechanically coupled feedback rails
- retractable wheels while retaining real pinball legs/levelers
- single external mains feed with branch distribution
- independent `AUDIO ONLY` Bluetooth mode
- USB/service bulkhead access
- fabrication targeted to Cutter CNC in Brazil

## Manufacturing caution

No hardware dimensions, wire gauges, fuse values, current capacities or safety-critical construction details from video content are accepted into the production design without cross-checking against manufacturer documentation and/or independent engineering references.

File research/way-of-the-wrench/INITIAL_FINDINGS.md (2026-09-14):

# Initial findings from Way of the Wrench ecosystem

These are early reference findings only. They are not production specifications.

## Series identity

- The original playlist is the creator's detailed DIY / budget virtual-pinball cabinet series and is widely used by builders as a scratch-build reference.
- The later `Big Budget VPin` series uses a flat-pack cabinet as the base and deliberately focuses on a higher-end build with more expensive displays, electronics and feedback hardware.

## Creator-provided companion files

The creator publishes downloadable cabinet configuration files on the South Delta Secondary School / Way of the Wrench resource page.

### Original generation

The older cabinet configuration uses a Teensy strip controller and defines addressable-lighting toys for:

- left side playfield
- right side playfield
- matrix
- speaker lighting
- under-cabinet lighting
- backbox lighting

This proves that addressable lighting was integrated as a cabinet-wide subsystem rather than a single decorative strip.

### Big Budget generation (September 2025 file)

The later published configuration uses a Wemos D1 Mini Pro-style strip controller setup and defines a more extensive layout including:

- 96 x 16 matrix definition
- right playfield strip: 134 LEDs
- left playfield strip: 134 LEDs
- backbox strip: 304 LEDs
- right speaker: 128 LEDs
- left speaker: 128 LEDs
- under-cabinet: 346 LEDs
- right magna-save: 4 LEDs
- flippers: 8 LEDs
- left magna-save: 4 LEDs

The exact physical implementation and electrical loading must still be checked against the videos and hardware documentation before reuse.

## Controller-board direction

Community discussion around the Big Budget series indicates use of Arnoz-family boards in the later build. A community schematic created specifically to mirror the Big Budget build mentions Walter/MOS8 and an alternate implementation using two Bunny Boards. This is useful as a map of the ecosystem, not as authoritative wiring documentation.

For our cabinet, controller choice remains open until we compare:

- Arnoz board stack
- Cleveland Software Design / PinOne ecosystem
- current DOF compatibility
- Linux/Windows software requirements
- Brazilian availability and replacement cost
- number and voltage/current class of intended toys

## Design lessons already applicable

1. Build the physical layout around verified component dimensions rather than nominal screen sizes.
2. Plan service access before finalizing cabinet openings; builders who lacked a sufficiently large rear opening lost the option for a sliding PC shelf.
3. Threaded inserts / machine-fastened modules are preferable for repeatedly serviced hardware.
4. Quick-disconnect connectors and labeling materially improve maintainability in a fully populated cabinet.
5. Separate and intentionally route power, controls, video/data and speaker wiring.
6. Addressable LEDs should be treated as a power/distribution subsystem, not merely decoration.
7. SSF exciter placement and mechanical toy placement should be reserved before electronics shelves consume the available wall/floor area.
8. High-end builds accumulate many boards and wires; modular removable panels/shelves are therefore a core requirement, not an aesthetic extra.
9. Mechanical feedback, SSF, shaker and knocker are all independently useful; our architecture should allow staged installation without rebuilding the cabinet.
10. Do not order the entire electronics BOM too early. Board ecosystems and component choices change; freeze each subsystem before purchasing it.

## Differences from our design

We will not directly reproduce either build. In particular:

- CNC-first joinery replaces hand-tool / pocket-hole-centric construction.
- Our playfield is an LG OLED42C5 in an independently supported VESA cradle.
- Service position uses dual gas struts plus independent mechanical safety support.
- PC is planned on a full-extension service drawer using an open-frame ATX chassis.
- Main audio must support independent Bluetooth `AUDIO ONLY` operation with the PC/screens/DOF powered down.
- Real Williams legs remain grounded during play; mobility uses retractable wheels.
- Electronics shelves must avoid stiffening SSF-critical cabinet-wall zones.
- High-current mechanical toys and isolated logic/audio electronics receive distinct mounting and wiring treatment.

## Next research passes

Research should now proceed only when each subsystem becomes relevant:

1. Playfield cradle / monitor mounting
2. Power distribution and branch protection
3. Main controller / plunger / nudge
4. DOF output boards and high-current switching
5. Mechanical toys and spatial placement
6. SSF / subwoofer / amplifiers
7. Addressable lighting and matrix
8. Cable raceways / connectors / labeling
9. Cooling
10. Software/front-end configuration

This staged method keeps research context and token use bounded while still using the complete series as a long-term design reference.

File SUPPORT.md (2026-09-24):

# Support

Virtual Pinball Cabinet is a community engineering project. Support is best-effort and happens through the official GitHub repository.

Official project:

https://github.com/advpeterrobinson-hash/vpin-cabinet

## Where to ask

Use a GitHub issue when you have a reproducible project problem, design question, measurement contribution, or fabrication result.

Choose the closest issue template:

- **Bug report** — scripts, validation, generated CAD, documentation, or reproducible project defects.
- **Design proposal** — mechanical, electrical, CNC, service, or architecture changes.
- **Hardware measurement** — measured dimensions for hardware that blocks CNC release.
- **Manufacturing feedback** — CNC, material, assembly, tolerance, fit, or proof-test experience.

For a small documentation correction, a focused pull request is also welcome.

## Before opening an issue

Please include:

- the commit or release you used;
- affected part IDs or subsystem when known;
- actual measurements and datums when geometry is involved;
- screenshots/photos where useful;
- exact validation or error output for software/build failures;
- whether you changed the design before the problem occurred.

Do not report an old dimension from a historical branch as a current defect without first checking the active project status.

## Security and safety

For information-security vulnerabilities, follow [SECURITY.md](SECURITY.md).

For mechanical, electrical, thermal, fire, structural, or service hazards, follow the physical-safety reporting instructions in [SECURITY.md](SECURITY.md).

## Manufacturing status

A public source file is not automatically approved for CNC production.

Check the project status, hardware-freeze matrix, measurement gates, and proof-test requirements before fabrication.

## Commercial support

The open-source licence permits commercial fabrication and support services. The official project does not currently guarantee private engineering support, fabrication service, response times, or warranty.

Commercial users remain responsible for satisfying the licence, applicable laws, electrical requirements, product-safety obligations, and any certification requirements that apply to products they make or sell.

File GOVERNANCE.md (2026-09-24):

# Project Governance

## Project model

Virtual Pinball Cabinet is an open-source hardware project maintained in public through GitHub.

The maintainer is responsible for accepting changes into the official project, protecting the engineering baseline, and deciding when a design state is ready for prototype, CNC release, or tagged release.

Contributors are encouraged to propose alternatives, measurements, tests, fixes, fabrication experience, and complete subsystems.

## Decision making

Engineering decisions are made primarily from:

1. safety;
2. manufacturability;
3. reproducibility;
4. structural/mechanical evidence;
5. serviceability;
6. compatibility with the project's flat-pack goals;
7. simplicity and part-count reduction where strength is not compromised.

Major decisions should be recorded in project documentation or issue/PR discussion so later contributors can understand why a geometry or constraint exists.

## Maintainer discretion

Acceptance of a contribution is not guaranteed solely because it is functional. The official project may choose a different approach when it is safer, simpler, easier to manufacture, more reusable, or better supported by measurements.

Forks and alternative implementations are permitted under `LICENSE`, subject to the reciprocal and Notice obligations.

## No proprietary fork requirement

Commercial participation is welcome. Companies and individuals may sell products and services based on the project.

If Covered Source or Products are conveyed, the reciprocal obligations of CERN-OHL-S-2.0 apply. Improvements cannot be converted into a closed proprietary derivative merely because the implementation is commercial.

## Contributions

Inbound contributions use the same CERN-OHL-S-2.0 licence as the project. See `CONTRIBUTING.md`.

The project does not currently require copyright assignment or a contributor licence agreement.

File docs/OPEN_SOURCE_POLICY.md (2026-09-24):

# Open-Source Policy

## Licence

The official Virtual Pinball Cabinet project is released under the **CERN Open Hardware Licence Version 2 — Strongly Reciprocal (CERN-OHL-S-2.0)**.

The definitive legal terms are in the repository's `LICENSE` file.

Official Source Location:

https://github.com/advpeterrobinson-hash/vpin-cabinet

## What this means

You may study, copy, modify, manufacture, use, and commercially sell products based on the project, subject to the licence.

The project intentionally permits commercial use. Open source does not mean that a fabricated cabinet, kit, consulting service, installation, or support service must be provided at zero price.

The strong-reciprocal requirement is about keeping the **design/source open**.

When you convey modified Covered Source or a Product based on it, CERN-OHL-S-2.0 requires the applicable Complete Source to be provided or made available from a Source Location, requires modification/source-location notices where applicable, and requires modified Covered Source to remain under the same reciprocal licence.

Under the strongly reciprocal variant, incorporating Covered Source into a larger design can make that larger work modified Covered Source, subject to the licence's definitions and exceptions for Available Components.

## What "free" means here

The project's requirement is **source freedom and reciprocity**, not zero-price commerce.

A fabricator or company may charge for physical cabinets, kits, parts, labor, integration, support, or other services. When the licence's Conveyance conditions are triggered, the applicable Complete Source and modifications must be made available under CERN-OHL-S-2.0 as required by the licence.

Private experimentation that is not Conveyed does not create a project-specific publication requirement beyond the actual CERN-OHL-S-2.0 terms.

## Required project attribution

The project's `NOTICE.md` specifies the original official Source Location and the manner in which it must be displayed for Products based on the project.

The original project link must remain with applicable Notices:

https://github.com/advpeterrobinson-hash/vpin-cabinet

A modified project should additionally identify the Source Location for its own modified Complete Source.

## Improvements and forks

Forks are welcome.

If a fork or commercial derivative is conveyed, improvements to Covered Source cannot simply be closed and withheld contrary to the reciprocal terms. The modified source must remain available under CERN-OHL-S-2.0 as required by the licence.

Private experimentation that is never conveyed is treated according to the actual licence text; this policy does not attempt to add restrictions beyond CERN-OHL-S-2.0.

## Contributions back upstream

Contributors are encouraged, but not forced by project process, to send useful changes back to the official repository as pull requests.

The legal reciprocal obligations are governed by `LICENSE`; contributing specifically to the upstream repository is not a substitute for satisfying those obligations.

## Scope

Unless a file states otherwise, CERN-OHL-S-2.0 applies to original project source in this repository, including hardware-design material, CAD source, drawings, configuration/design data, build/generation scripts, validation code, BOMs, and project documentation.

Third-party material is not relicensed. See `THIRD_PARTY_NOTICES.md`.

## Plain-language summary only

This document is intended to explain project policy. It does not replace or modify the legal terms in `LICENSE`.

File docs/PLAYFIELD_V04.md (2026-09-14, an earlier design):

# Playfield Service v0.4

Status: **engineering provisional — not for manufacturing or gas-strut purchase**.

## Objective

Create the first explicit kinematic model for the LG OLED42C5 playfield service system while preserving the Williams WPC standard-body external cabinet dimensions.

The v0.4 model is intentionally a packaging model. It answers whether the intended service concept can fit before detailed brackets, VESA plates, hinges, strut hardware, cable chains, or CNC pockets are finalized.

## Fixed inputs

- LG OLED42C5 physical envelope: 932 x 540 x 41.1 mm.
- OLED mass: 9.8 kg.
- Williams WPC cabinet baseline: 558.8 mm external width, 1308.1 mm side length, 400.05 mm front height, 596.9 mm rear height, 180.975 mm rear top flat.
- Nominal plywood: 18 mm.
- OLED installed cross-width target: 542 mm.
- Nominal OLED pocket depth: 9.6 mm/side.
- Nominal remaining outer side skin: 8.4 mm.
- Service opening target: 70 degrees relative to the closed playfield position.
- Dual gas struts plus an independent positive mechanical safety support are mandatory.

## Provisional assumptions introduced in v0.4

These are deliberately isolated in `config/playfield_v04.json` so they can change without corrupting the validated cabinet baseline.

- OLED front setback: 44.4 mm, based on the reference-build packaging position.
- Glass clearance normal to the playfield: 12 mm.
- Cradle mass estimate: 3.0 kg in addition to the 9.8 kg OLED.
- Cradle packaging rails: 20 x 20 mm envelopes.
- Hinge axis: 35 mm behind the OLED rear edge along the playfield slope.
- Hinge axis diameter envelope: 12 mm.
- First-pass gas-strut moving attachment: 400 mm forward of hinge.
- First-pass fixed attachment: 50 mm forward and 100 mm below hinge.
- First-pass gas-strut candidate: 300 N each, two struts.

None of those values are frozen hardware selections.

## Gas-strut calculation philosophy

The solver uses a 2D Y/Z side-view mechanism. It calculates:

- closed and open strut lengths;
- required stroke;
- effective moment arm;
- estimated force per strut required to balance the estimated OLED + cradle mass in the closed position;
- open-position assist/gravity ratio.

The model uses an approximate combined center of gravity at the OLED longitudinal midpoint. Actual cradle mass and center of gravity must replace this assumption before selecting struts.

The current candidate is expected to be in the neighborhood of a 300 N gas spring with roughly 125 mm stroke and ~345/471 mm closed/open pin-to-pin geometry, but catalog availability and bracket geometry have not been checked yet.

## FreeCAD objects generated

`tools/build_playfield_v04.py` adds a group named:

`PLAYFIELD SERVICE v0.4 - PROVISIONAL`

containing:

- LG OLED42C5 closed envelope;
- OLED 70-degree service-position ghost;
- hinge-axis envelope;
- provisional closed cradle rails;
- open cradle ghost;
- left/right gas-strut closed candidates;
- left/right gas-strut open ghosts.

The script is safe to rerun and removes only the group it owns.

## Validation gate before v0.5

Before this branch can be considered a validated engineering checkpoint:

1. `tools/validate.py` must still pass the cabinet/OLED baseline.
2. `tools/solve_playfield_struts.py` must pass its broad packaging guards.
3. `freecadcmd tools/build_playfield_v04.py` must complete without fatal errors.
4. The generated FreeCAD document must open and show the OLED/cradle opening toward the service position rather than through the cabinet floor.
5. The hinge location and open envelope must look mechanically plausible relative to the cabinet rear.
6. No gas strut may be purchased yet.

## Next stage after validation

v0.5 will refine the cradle into actual structural members and bracket interfaces, establish the independent safety prop/lock, and begin collision sweeps against the backbox/service envelope. Exact VESA hole placement waits for an LG mechanical drawing or physical measurement rather than being invented.

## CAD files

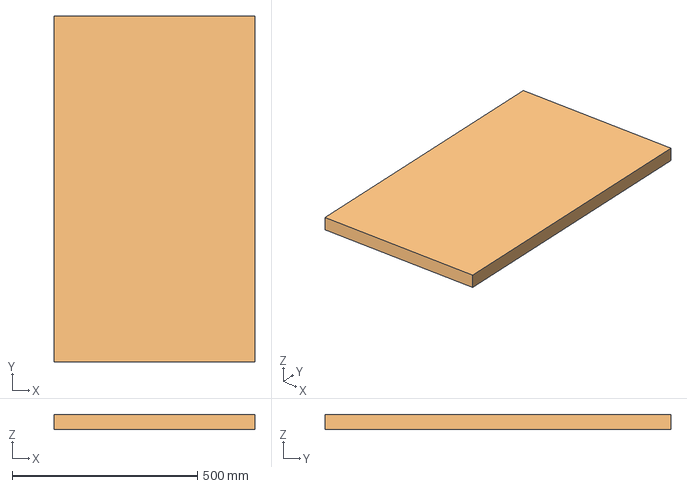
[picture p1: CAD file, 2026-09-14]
cad/master/vpin-master.FCStd
542.0 x 932.0 x 41.1 mm
LG OLED42C5 Physical Envelope
C5 Required Cross-Width + Clearance

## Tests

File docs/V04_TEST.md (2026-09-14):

# v0.4 local test

After fetching the branch:

```bash
bash tools/run_playfield_v04.sh
freecad cad/master/vpin-master.FCStd
```

In FreeCAD select **PLAYFIELD SERVICE v0.4 - PROVISIONAL** and use an axonometric view + Fit All.

Expected visual result: the solid/less-transparent OLED remains in the closed playfield position; a highly transparent ghost rotates upward about the rear hinge axis by 70 degrees; matching cradle and gas-strut ghosts show the service geometry.

Do not manually edit the generated v0.4 objects. Report any FreeCAD console error or obviously inverted/open-downward geometry; the build script will be corrected instead.

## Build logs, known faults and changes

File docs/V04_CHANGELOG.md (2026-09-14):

# v0.4 engineering scope

- Add a first-pass 70-degree hinged playfield service model for the LG OLED42C5.
- Add explicit hinge-axis packaging geometry.
- Add provisional 20 mm cradle-rail envelopes.
- Add a two-strut side-view geometry solver and closed/open strut envelopes.
- Keep all new mechanism values explicitly provisional and separate from the validated Williams cabinet baseline.
- Require an independent mechanical safety support regardless of gas-strut selection.
- Do not approve CNC pockets, hinge brackets, VESA bracket geometry, or gas-strut purchasing in this stage.

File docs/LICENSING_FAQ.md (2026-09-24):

# Licensing FAQ

This page is a plain-language guide to the project's licensing policy. It does not replace the legal text in [LICENSE](../LICENSE).

## What licence does the project use?

Original project material is released under the **CERN Open Hardware Licence Version 2 — Strongly Reciprocal (CERN-OHL-S-2.0)** unless a file explicitly states otherwise.

Official project / Source Location:

**https://github.com/advpeterrobinson-hash/vpin-cabinet**

See also [NOTICE.md](../NOTICE.md) and [THIRD_PARTY_NOTICES.md](../THIRD_PARTY_NOTICES.md).

## Can I build one for myself?

Yes. You may study, modify, and make Products from the Covered Source subject to the licence.

## Can I sell cabinets, kits, parts, or services?

Yes. Commercial use is allowed.

You may charge for fabricated cabinets, flat-pack kits, parts, assembly, installation, support, consulting, or related services.

The reciprocal obligation concerns the design/source. When you Convey modified Covered Source or Products based on it, the applicable Complete Source must be provided or made available under the licence as required by CERN-OHL-S-2.0.

## Do I have to publish every private experiment?

No project-specific rule requires publication of changes that remain private and are never Conveyed. The actual CERN-OHL-S-2.0 text controls.

If you later Convey a Product based on modified Covered Source, the licence's source-availability and Notice obligations apply.

## If I improve the design and sell the improved version, can I keep the improvements proprietary?

Not if doing so would conflict with the strongly reciprocal licence.

CERN-OHL-S-2.0 requires modified Covered Source to remain under the same licence when conveyed, and Products must be accompanied by Complete Source or a Source Location as specified by the licence.

## Must the source be available at zero price?

The licence requires source availability under its terms; it does not require physical Products or services to be sold at zero price.

This project's phrase "keep improvements free" means **keep the design/source open and reusable under the same reciprocal licence**.

## Do I have to link the official project?

Preserve the project Notices.

The project's Source Location Notice identifies the official project:

**https://github.com/advpeterrobinson-hash/vpin-cabinet**

[NOTICE.md](../NOTICE.md) specifies the attribution wording and how the Source Location is displayed for Products.

A modified fork should also identify the Source Location for its own modified Complete Source where required by the licence.

## Do I have to submit my changes back to the official repository?

A pull request back upstream is strongly encouraged because it helps everyone share improvements, but upstream contribution is not itself the legal test.

The legal obligations are the ones in [LICENSE](../LICENSE).

## Can I create a fork?

Yes. Forks and alternative implementations are welcome, subject to the licence and Notices.

Please make it clear when a fork is not the official project, and do not imply endorsement by the original maintainers.

## What about third-party parts, manuals, artwork, ROMs, or trademarks?

They keep their original rights and licences.

The project's licence does not magically relicense third-party content. See [THIRD_PARTY_NOTICES.md](../THIRD_PARTY_NOTICES.md).

Do not contribute proprietary CAD, copyrighted manuals, game assets, ROMs, artwork, or other restricted material unless redistribution rights are clear.

## What licence applies to contributions?

By submitting material to the official repository, contributors confirm that they have the right to submit it and provide it under the project's applicable licence. See [CONTRIBUTING.md](../CONTRIBUTING.md).

## Is the design already safe or manufacturing-ready because it is open source?

No.

Public availability is not a certification, conformity assessment, engineering approval, or manufacturing release. Follow the project's hardware-freeze gates, proof tests, warnings, and release status.

## Where is the authoritative legal text?

[LICENSE](../LICENSE).

This FAQ and the other policy documents explain project intent but do not modify the licence.

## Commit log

2026-09-14 Ignore local CAD audit workspace
2026-09-14 Create parametric cabinet shell baseline
    [vpin-master.FCStd]
2026-09-14 Build parametric Williams WPC cabinet profile
    [vpin-master.FCStd]
2026-09-14 Add LG C5 fit-check and playfield mechanical audits
    [vpin-master.FCStd]
2026-09-14 Model provisional hinged playfield service system v0.4
    * Add provisional playfield service geometry
    * Add gas-strut geometry solver
    * Add playfield cradle kinematic model
    * Add one-command v0.4 local runner
    * Document v0.4 playfield service design
    * Add compact v0.4 test instructions
    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
2026-09-15 Model playfield sweep, backbox keepout, and safety prop v0.5
    * Add v0.5 sweep and safety configuration
    * Add v0.5 sweep and safety solver
    * Build v0.5 sweep and safety geometry
    * Add explicit FreeCADCmd v0.5 entry point
    * Add v0.5 headless geometry verification
    * Add one-command v0.5 local validation runner
    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
2026-09-15 Increase playfield replacement envelope to 560 mm
2026-09-15 Accept 580 mm future-proof main body baseline
2026-09-24 docs: publish open-source licensing and contributor framework
    Adopt CERN-OHL-S-2.0 on the default branch and add Source Location, contribution, governance, security, third-party, issue/PR, and citation documentation.
2026-09-27 docs: expose current gallery on default landing and remove obsolete gas assistance
2026-10-09 docs: identify V35.1 as current review and preserve manufacturing holds
2026-10-21 docs: add text-to-cad tooling assessment
2026-10-21 docs: add Portuguese text-to-cad assessment
2026-10-21 docs: align agent instructions with current V35.1 records
